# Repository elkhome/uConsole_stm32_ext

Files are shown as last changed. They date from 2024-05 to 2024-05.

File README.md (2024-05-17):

# uConsole_stm32_ext
STM32 extension card for uConsole.

Design is not finished and has not been tested.

Design based on dotcypress's uHub board, with identical USB port positioning: https://github.com/dotcypress/uhub

STM32 design learned from Sleepdealr's Kingsaver Replacement PCB: https://github.com/Sleepdealr/Kingsaver-Replacement-PCB

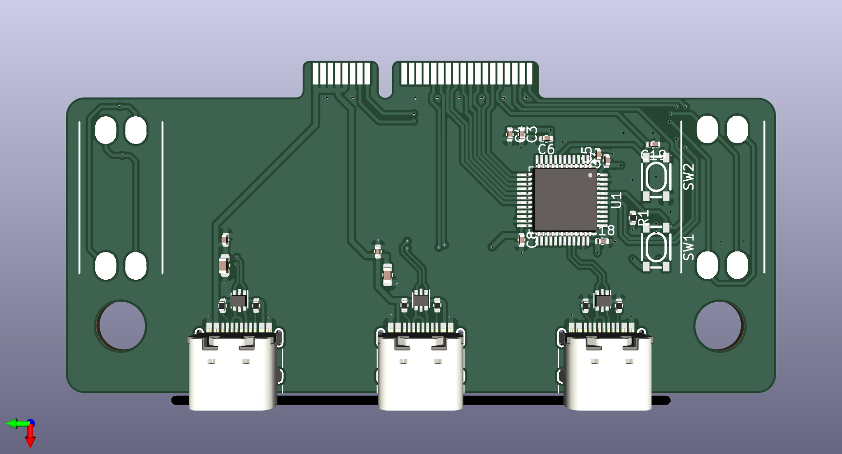
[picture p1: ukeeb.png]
3D render of board


The goal is to get some of the functionality of both boards together, at a slightly lower manufacturing cost.

- Two USB C ports connected directly to the USB C pins, to avoid the need for a USB hub.
- STM32 replacing the RP2040, to avoid the need for crystal or flash components.
- Connecting the microcontroller to the uConsole via GPIO instead of USB, to both preserve uConsole’s USB lines and make the microcontroller’s USB lines externally accessible.
- Same USB C ports in the same position as the uHub, so the same faceplate should work for both.

With a CM4, you’d be able to program the STM32 over UART or I2C. With any other core, it will still work, but if they don’t have UART or I2C support for those pins, you might need to program the STM32 externally over USB.

The pins to program and reset the STM32 would be accessible either by physical button or over GPIO.

My main goal for the STM32 would be to use it as a USB HID device, sending keyboard commands to a headless computer over USB.

If I can find physical space on the board, I might also try to break out more microcontroller pins to possibly allow myself to solder in a sensor or LEDs or something.

Power management is dependent on the uConsole (there’s no on-board linear regulator, and the device USB port has it’s power line disconnected). In theory, I could change this?

This is my first STM32 project and my first fully assembled PCB project (I’ve only done keyboards before), so I’m not entirely sure what I’m doing.

https://forum.clockworkpi.com/t/stm32-ext-board-concept-thoughts/13368

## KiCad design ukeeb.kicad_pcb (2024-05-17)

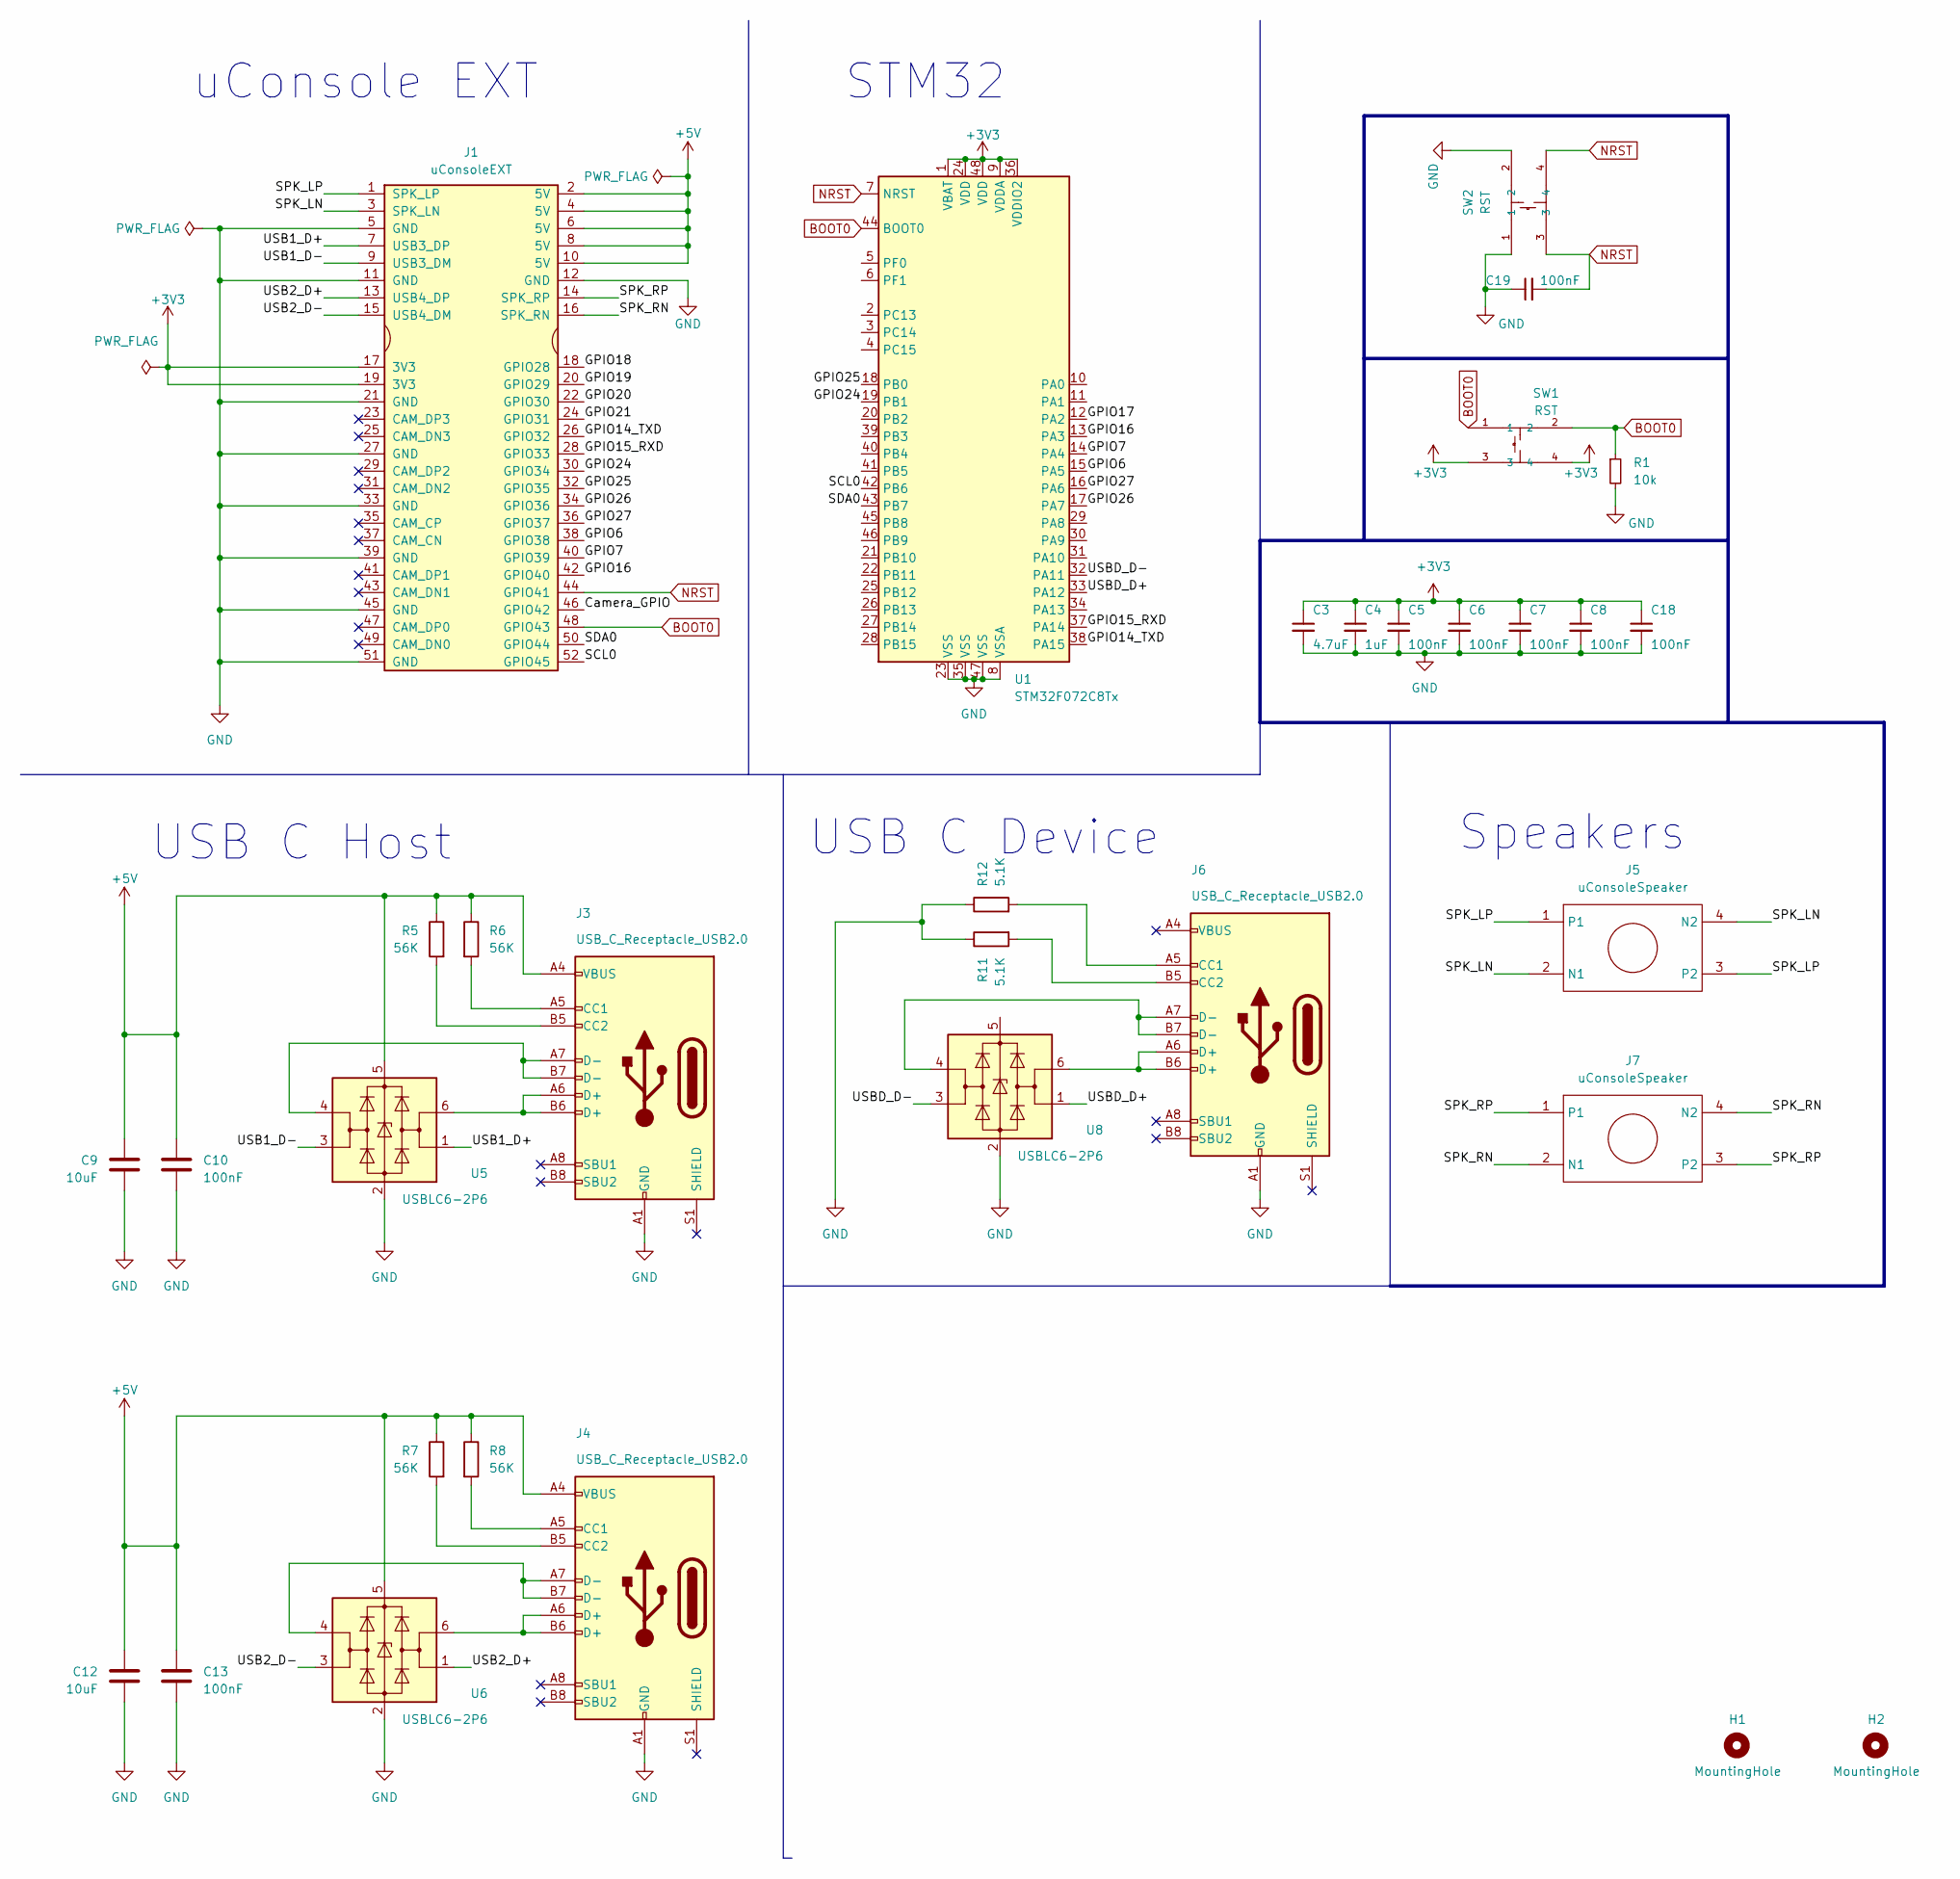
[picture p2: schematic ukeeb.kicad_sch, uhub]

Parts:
C3: 4.7uF; C_0402_1005Metric; LCSC C52923
C4: 1uF; C_0402_1005Metric; LCSC C52923
C5, C6, C7, C8, C18, C19: 100nF; C_0402_1005Metric; LCSC C307331
C9, C12: 10uF; C_0603_1608Metric
C10, C13: 100nF; C_0402_1005Metric
H1, H2: MountingHole; MountingHole_5.3mm_M5
J1: uConsoleEXT; ext
J3, J4, J6: USB_C_Receptacle_USB2.0; USB_C_Receptacle_HRO_TYPE-C-31-M-12
J5, J7: uConsoleSpeaker; speaker
R1: 10k; R_0402_1005Metric
R5, R6, R7, R8: 56K; R_0402_1005Metric
R11, R12: 5.1K; R_0402_1005Metric
SW1, SW2: RST; KEY-SMD_4P-L4.2-W3.2-P2.20-LS4.6; LCSC C139797
U1: STM32F072C8Tx; LQFP-48_7x7mm_P0.5mm
U5, U6, U8: USBLC6-2P6; SOT-666

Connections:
+3V3: C3.1, C4.1, C5.1, C6.1, C7.1, C8.1, C18.1, J1.17 (3V3), J1.19 (3V3), SW1.3, SW1.4, U1.1 (VBAT), U1.9 (VDDA), U1.24 (VDD), U1.36 (VDDIO2), U1.48 (VDD)
+5V: C9.2, C10.2, C12.2, C13.2, J1.2 (5V), J1.4 (5V), J1.6 (5V), J1.8 (5V), J1.10 (5V), J3.A4 (VBUS), J3.A9 (VBUS), J3.B4 (VBUS), J3.B9 (VBUS), J4.A4 (VBUS), J4.A9 (VBUS), J4.B4 (VBUS), J4.B9 (VBUS), R5.1, R6.1, R7.1, R8.1, U5.5 (VBUS), U6.5 (VBUS)
/Camera_GPIO: J1.46 (GPIO42)
/GPIO6: J1.38 (GPIO38), U1.15 (PA5)
/GPIO7: J1.40 (GPIO39), U1.14 (PA4)
/GPIO14_TXD: J1.26 (GPIO32), U1.38 (PA15)
/GPIO15_RXD: J1.28 (GPIO33), U1.37 (PA14)
/GPIO16: J1.42 (GPIO40), U1.13 (PA3)
/GPIO17: U1.12 (PA2)
/GPIO18: J1.18 (GPIO28)
/GPIO19: J1.20 (GPIO29)
/GPIO20: J1.22 (GPIO30)
/GPIO21: J1.24 (GPIO31)
/GPIO24: J1.30 (GPIO34), U1.19 (PB1)
/GPIO25: J1.32 (GPIO35), U1.18 (PB0)
/GPIO26: J1.34 (GPIO36), U1.17 (PA7)
/GPIO27: J1.36 (GPIO37), U1.16 (PA6)
/SCL0: J1.52 (GPIO45), U1.42 (PB6)
/SDA0: J1.50 (GPIO44), U1.43 (PB7)
/SPK_LN: J1.3 (SPK_LN), J5.2 (N1), J5.4 (N2)
/SPK_LP: J1.1 (SPK_LP), J5.1, J5.3 (P2)
/SPK_RN: J1.16 (SPK_RN), J7.2 (N1), J7.4 (N2)
/SPK_RP: J1.14 (SPK_RP), J7.1, J7.3 (P2)
/USB1_D+: J1.7 (USB3_DP), U5.1 (I/O1)
/USB1_D-: J1.9 (USB3_DM), U5.3 (I/O2)
/USB2_D+: J1.13 (USB4_DP), U6.1 (I/O1)
/USB2_D-: J1.15 (USB4_DM), U6.3 (I/O2)
/USBD_D+: U1.33 (PA12), U8.1 (I/O1)
/USBD_D-: U1.32 (PA11), U8.3 (I/O2)
BOOT0: J1.48 (GPIO43), R1.1, SW1.1, SW1.2, U1.44 (BOOT0)
GND: C3.2, C4.2, C5.2, C6.2, C7.2, C8.2, C9.1, C10.1, C12.1, C13.1, C18.2, C19.1, J1.5 (GND), J1.11 (GND), J1.12 (GND), J1.21 (GND), J1.27 (GND), J1.33 (GND), J1.39 (GND), J1.45 (GND), J1.51 (GND), J3.A1 (GND), J3.A12 (GND), J3.B1 (GND), J3.B12 (GND), J4.A1 (GND), J4.A12 (GND), J4.B1 (GND), J4.B12 (GND), J6.A1 (GND), J6.A12 (GND), J6.B1 (GND), J6.B12 (GND), R1.2, R11.1, R12.1, SW2.1, SW2.2, U1.8 (VSSA), U1.23 (VSS), U1.35 (VSS), U1.47 (VSS), U5.2 (GND), U6.2 (GND), U8.2 (GND)
NRST: C19.2, J1.44 (GPIO41), SW2.3, SW2.4, U1.7 (NRST)
unnamed: J3.A5 (CC1), R6.2
unnamed: J3.B5 (CC2), R5.2
unnamed: J3.A6 (D+), J3.B6 (D+), U5.6 (I/O1)
unnamed: J3.A7 (D-), J3.B7 (D-), U5.4 (I/O2)
unnamed: J4.A5 (CC1), R8.2
unnamed: J4.B5 (CC2), R7.2
unnamed: J4.A6 (D+), J4.B6 (D+), U6.6 (I/O1)
unnamed: J4.A7 (D-), J4.B7 (D-), U6.4 (I/O2)
unnamed: J6.A5 (CC1), R12.2
unnamed: J6.B5 (CC2), R11.2
unnamed: J6.A6 (D+), J6.B6 (D+), U8.6 (I/O1)
unnamed: J6.A7 (D-), J6.B7 (D-), U8.4 (I/O2)

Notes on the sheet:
uConsole EXT
STM32
Speakers
USB C Host
USB C Device

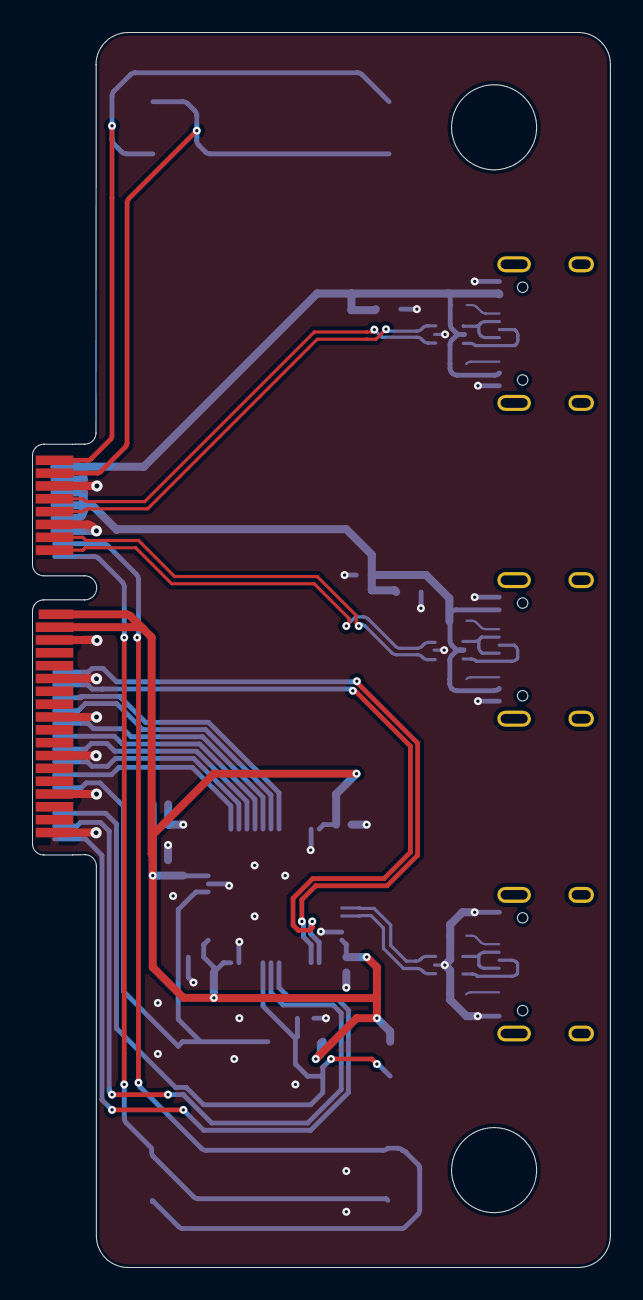
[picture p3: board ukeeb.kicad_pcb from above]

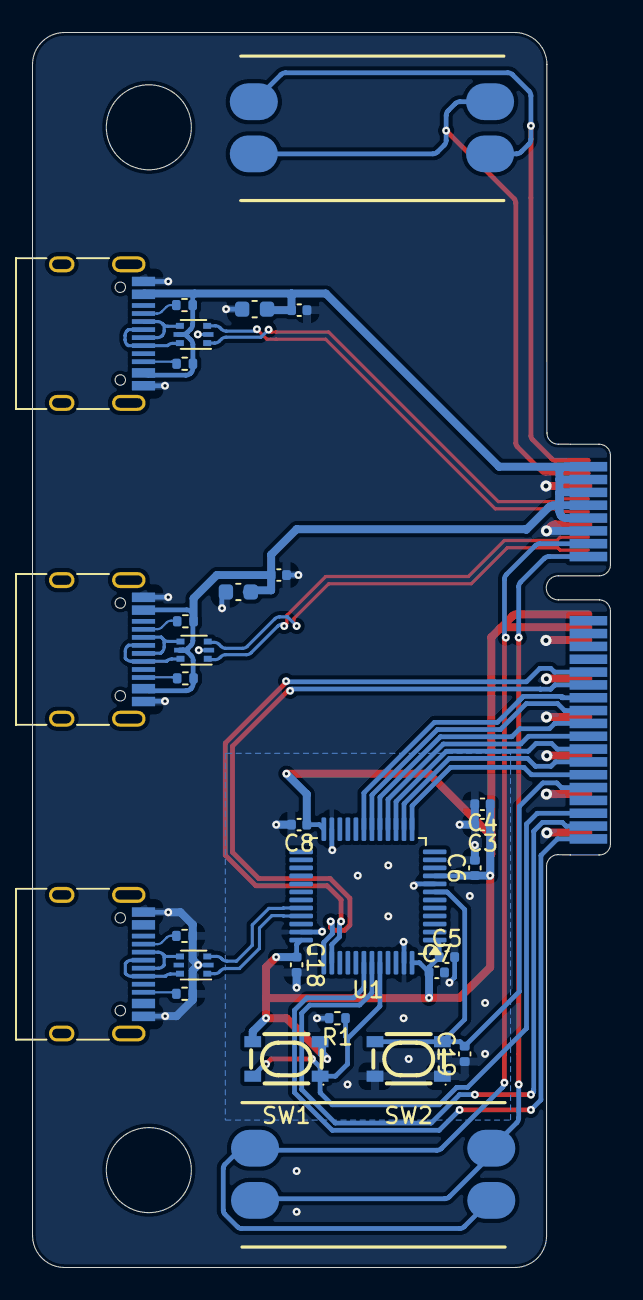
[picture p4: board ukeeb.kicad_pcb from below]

Board: 4 copper layers, 36.0 x 77.0 mm, 33 parts (30 on the bottom side), 38 nets.
